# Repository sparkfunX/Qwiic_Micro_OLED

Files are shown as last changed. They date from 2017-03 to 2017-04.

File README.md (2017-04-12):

Qwiic_Micro_OLED
========================================
Qwiic Micro_OLED

[*SPX-14269*](https://www.sparkfun.com/products/14269)

The Qwiic Micro OLED is a small monochrome, blue-on-black OLED. It’s "micro", but it still packs a punch – the OLED display is crisp, and you can fit a deceivingly large amount of graphics on there. This breakout is perfect for adding graphics to your next project or displaying diagnostic information without resorting to serial output.

The Qwiic version of the Micro OLED has two Qwiic connectors that allow you to easily and quickly attach the display to the Qwicc Shield of your choosing.The [Qwiic system](http://www.sparkfun.com/qwiic) enables fast and solderless connection between popular platforms and various sensors and actuators. You can read more about the Qwiic system [here](http://www.sparkfun.com/qwiic). 

License Information
-------------------

This product is _**open source**_!

Please review the LICENSE.md file for license information.

If you have any questions or concerns on licensing, please contact techsupport@sparkfun.com.

Distributed as-is; no warranty is given.

- Your friends at SparkFun.

_<COLLABORATION CREDIT>_

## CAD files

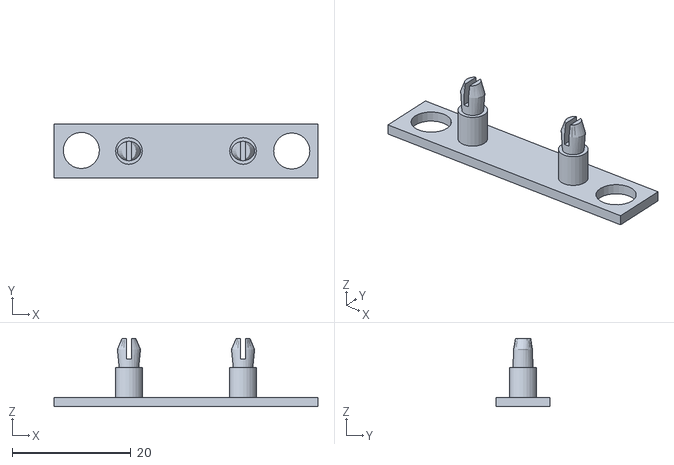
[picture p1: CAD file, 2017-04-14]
Mold/OLED_Suction_Holder.stl
44.5 x 9.18 x 11.5

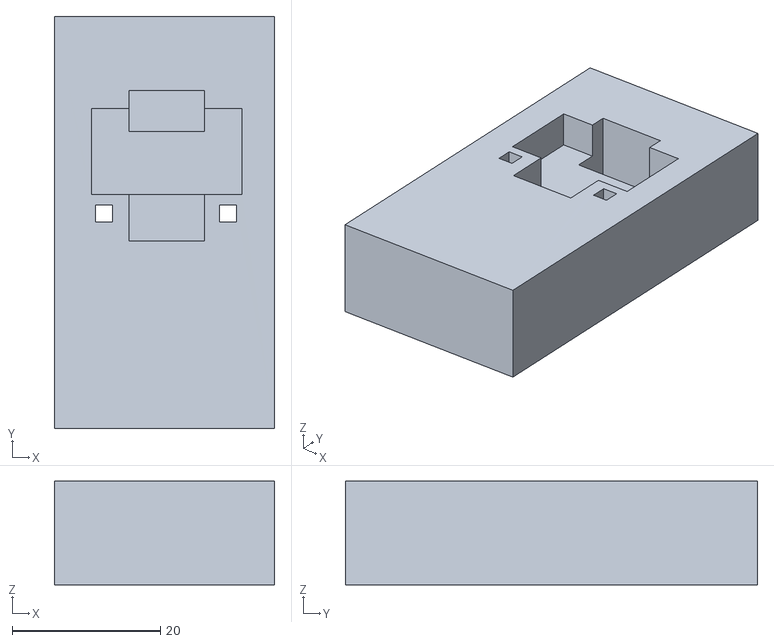
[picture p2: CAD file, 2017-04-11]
Mold/OLED_Soldering_Jig.stl
29.7 x 55.6 x 14.0

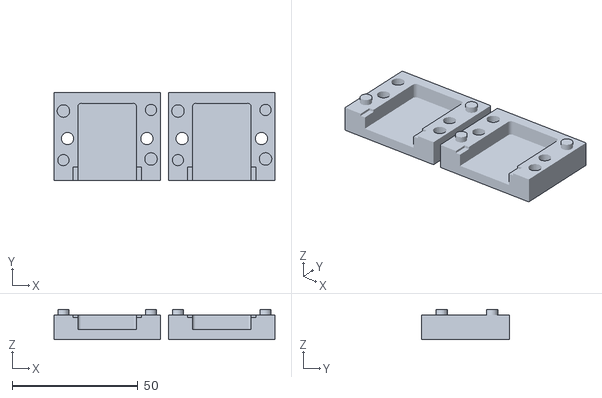
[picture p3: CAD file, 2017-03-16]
Mold/Qwiic_OLED_Mold_MillVersionV2.stl
87.9 x 35.0 x 12.0

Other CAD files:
Mold/OLED_Soldering_Jig.skp
Mold/OLED_Suction_Holder.skp
Mold/Qwiic_OLED_Mold_MillVersionV2.skp
Mold/Qwiic_OLED_Mold_MillVersionV3.skp

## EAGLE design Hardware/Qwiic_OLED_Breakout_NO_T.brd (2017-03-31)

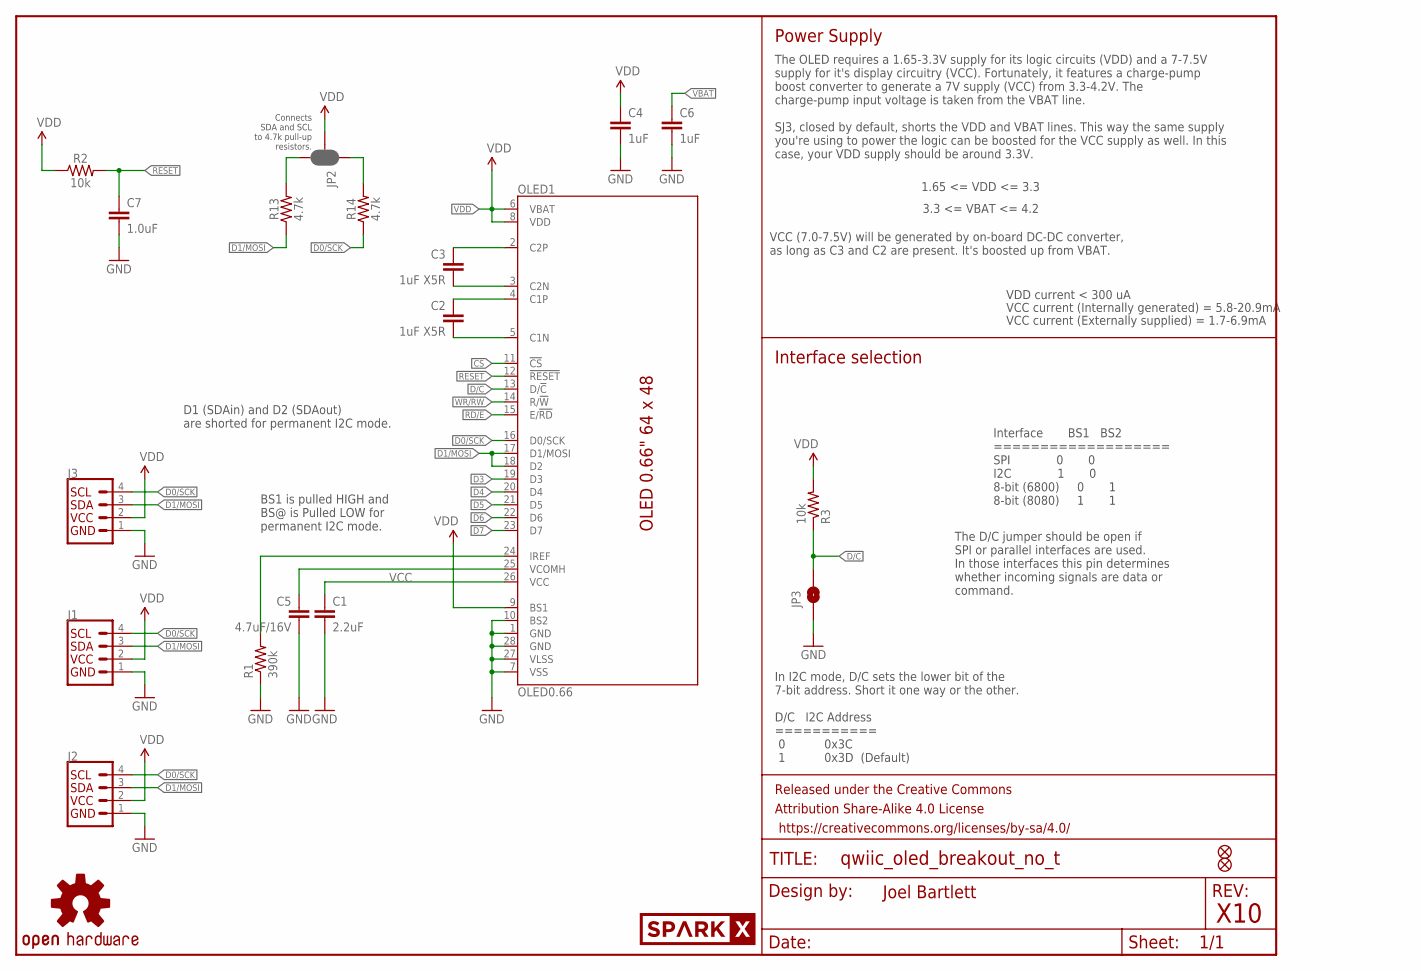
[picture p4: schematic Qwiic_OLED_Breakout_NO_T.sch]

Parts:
C1: 2.2uF; 0805
C2, C3: 1uF X5R; 0805
C4, C6: 1uF; 0603-CAP
C5: 4.7uF/16V; 1206
C7: 1.0uF; 0603
FID1, FID2: FIDUCIAL1X2; FIDUCIAL-1X2
FRAME1: FRAME-LETTER; CREATIVE_COMMONS
J1, J2: I2C_STANDARDJS-1MM; 1X04_1MM_RA
J3: I2C_STANDARD_NO_SILK; 1X04_NO_SILK
JP2: JUMPER-SMT_3_2-NC_PASTE_SILK; SMT-JUMPER_3_2-NC_PASTE_SILK
JP3: JUMPER-SMT_2_NO_SILK; SMT-JUMPER_2_NO_SILK
LOGO3: OSHW-LOGOS; OSHW-LOGO-S
OLED1: OLED0.66; OLED-0.66-64X48
R1: 390k; 0603-RES
R2: 10k; 0603
R3: 10k; 0603-RES
R13, R14: 4.7k; 0603
U$3: SPARKX-LOGO2; SPARKX-TINY

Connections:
C1N: C2.2, OLED1.5 (C1N)
C1P: C2.1, OLED1.4 (C1P)
C2N: C3.2, OLED1.3 (C2N)
C2P: C3.1, OLED1.2 (C2P)
CS: OLED1.11 (!CS!)
D0/SCK: J1.4 (SCL), J2.4 (SCL), J3.4 (SCL), OLED1.16 (D0/SCK), R14.1
D1/MOSI: J1.3 (SDA), J2.3 (SDA), J3.3 (SDA), OLED1.17 (D1/MOSI), OLED1.18 (D2), R13.1
D3: OLED1.19 (D3)
D4: OLED1.20 (D4)
D5: OLED1.21 (D5)
D6: OLED1.22 (D6)
D7: OLED1.23 (D7)
D/C: JP3.2, OLED1.13 (D/!C!), R3.1
GND: C1.2, C4.2, C5.2, C6.2, C7.2, J1.1 (GND), J2.1 (GND), J3.1 (GND), JP3.1, OLED1.1 (GND), OLED1.7 (VSS), OLED1.10 (BS2), OLED1.27 (VLSS), OLED1.28 (GND), R1.1
IREF: OLED1.24 (IREF), R1.2
unnamed: JP2.3, R13.2
unnamed: JP2.1, R14.2
RD/E: OLED1.15 (E/!RD!)
RESET: C7.1, OLED1.12 (!RESET!), R2.2
VBAT: C6.1
VCC: C1.1, OLED1.26 (VCC)
VCOMH: C5.1, OLED1.25 (VCOMH)
VDD: C4.1, J1.2 (VCC), J2.2 (VCC), J3.2 (VCC), JP2.2, OLED1.6 (VBAT), OLED1.8 (VDD), OLED1.9 (BS1), R2.1, R3.2
WR/RW: OLED1.14 (R/!W!)

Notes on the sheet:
X10
1.65 <= VDD <= 3.3
VDD current < 300 uA
VCC current (Internally generated) = 5.8-20.9mA
VCC current (Externally supplied) = 1.7-6.9mA
Interface BS1 BS2 =================== SPI 0 0 I2C 1 0 8-bit (6800) 0 1 8-bit (8080) 1 1
VCC (7.0-7.5V) will be generated by on-board DC-DC converter, as long as C3 and C2 are present. It's boosted up from VBAT.
3.3 <= VBAT <= 4.2
Interface selection
D1 (SDAin) and D2 (SDAout) are shorted for permanent I2C mode.
In I2C mode, D/C sets the lower bit of the 7-bit address. Short it one way or the other. D/C I2C Address =========== 0 0x3C 1 0x3D (Default)
Power Supply
The OLED requires a 1.65-3.3V supply for its logic circuits (VDD) and a 7-7.5V supply for it's display circuitry (VCC). Fortunately, it features a charge-pump boost converter to generate a 7V supply (VCC) from 3.3-4.2V. The charge-pump input voltage is taken from the VBAT line. SJ3, closed by defau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
The D/C jumper should be open if SPI or parallel interfaces are used. In those interfaces this pin determines whether incoming signals are data or command.
BS1 is pulled HIGH and BS@ is Pulled LOW for permanent I2C mode.
Connects SDA and SCL to 4.7k pull-up resistors.
Joel Bartlett

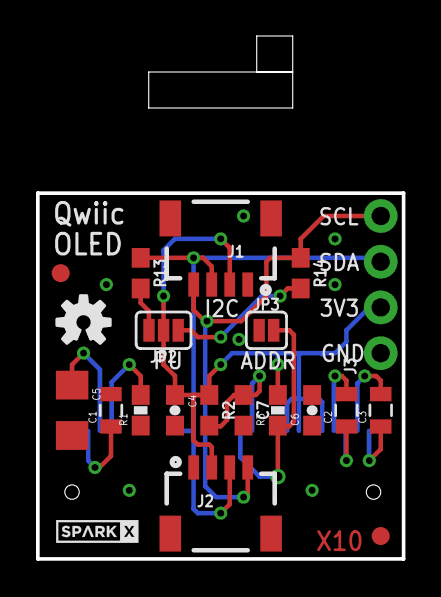
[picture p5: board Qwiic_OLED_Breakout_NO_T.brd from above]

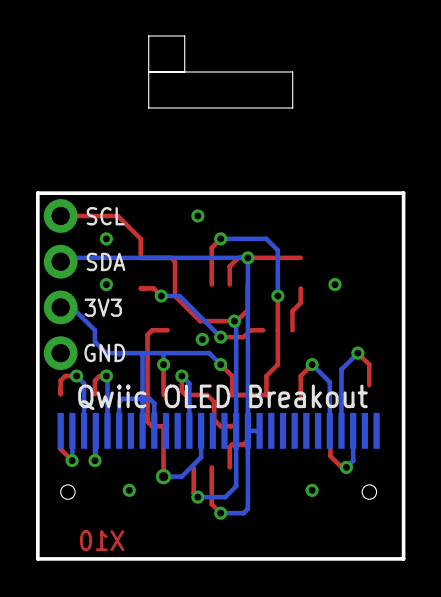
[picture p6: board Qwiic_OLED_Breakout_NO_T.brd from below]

Board: 2 copper layers, 20.3 x 20.3 mm, 23 parts (2 on the bottom side), 15 nets.

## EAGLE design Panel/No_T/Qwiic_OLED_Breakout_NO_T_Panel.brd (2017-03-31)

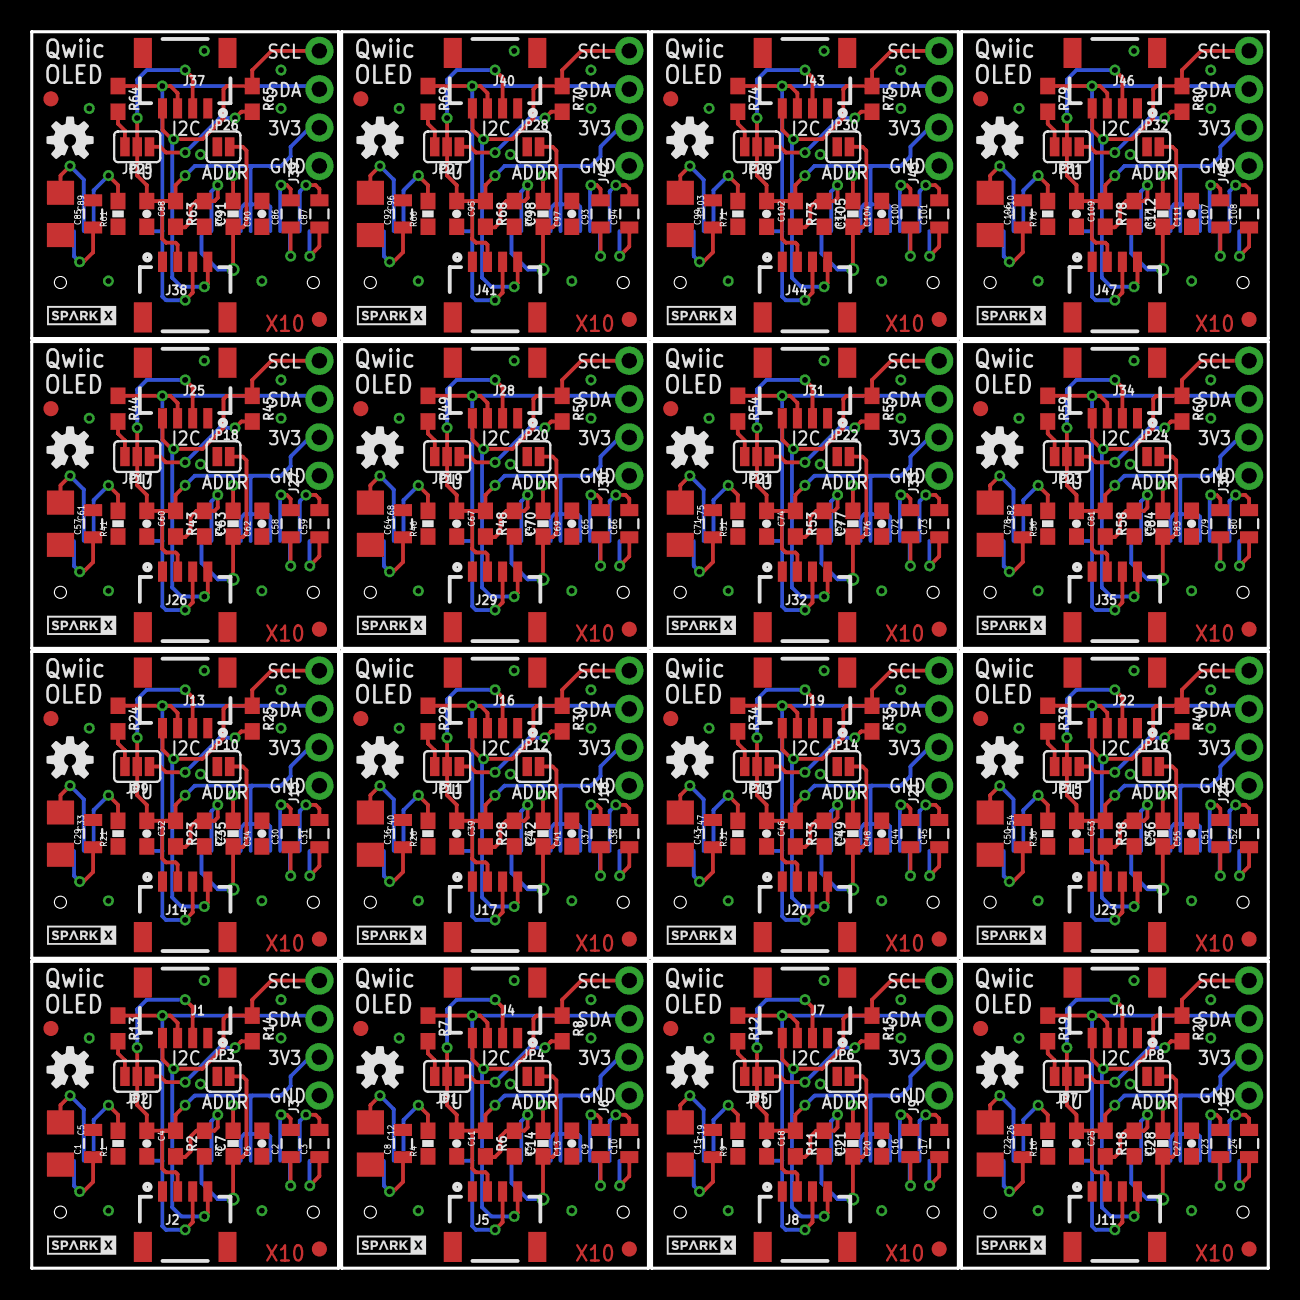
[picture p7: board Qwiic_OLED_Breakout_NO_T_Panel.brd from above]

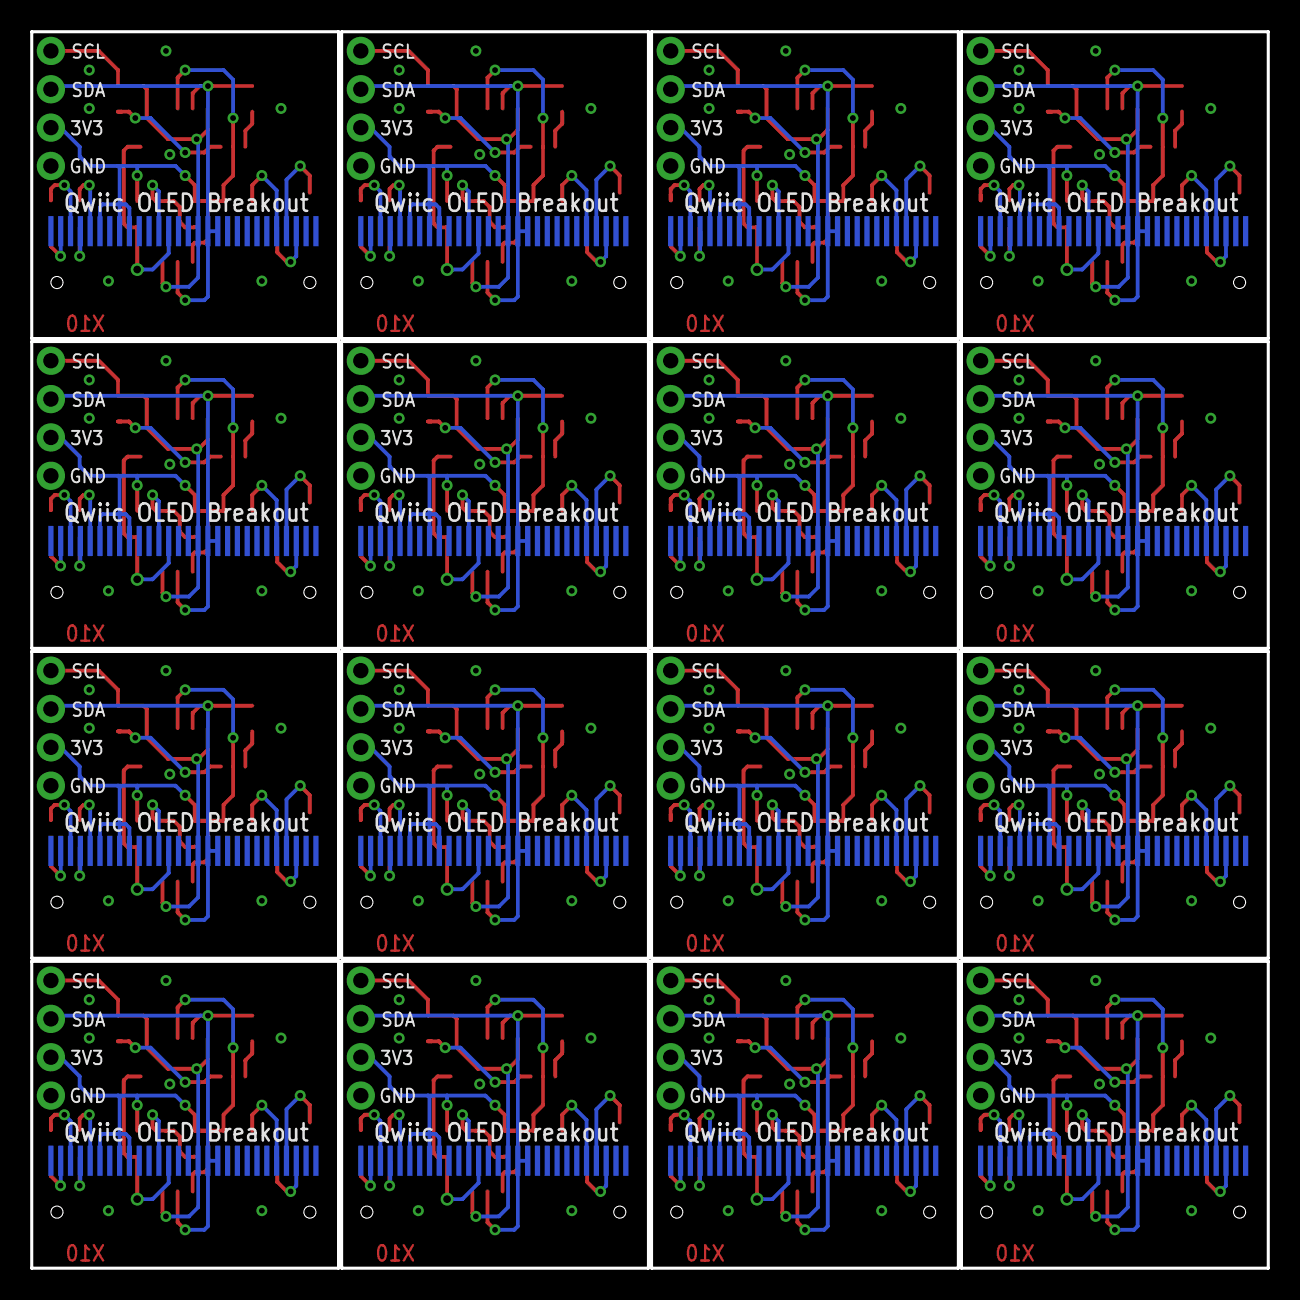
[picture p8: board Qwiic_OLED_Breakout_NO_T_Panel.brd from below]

Board: 2 copper layers, 81.9 x 81.9 mm, 352 parts (16 on the bottom side), 240 nets.

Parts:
C1, C8, C15, C22, C29, C36, C43, C50, C57, C64, C71, C78, C85, C92, C99, C106: 2.2uF; 0805
C2, C3, C9, C10, C16, C17, C23, C24, C30, C31, C37, C38, C44, C45, C51, C52, C58, C59, C65, C66, C72, C73, C79, C80, C86, C87, C93, C94, C100, C101, C107, C108: 1uF X5R; 0805
C4, C6, C11, C13, C18, C20, C25, C27, C32, C34, C39, C41, C46, C48, C53, C55, C60, C62, C67, C69, C74, C76, C81, C83, C88, C90, C95, C97, C102, C104, C109, C111: 1uF; 0603-CAP
C5, C12, C19, C26, C33, C40, C47, C54, C61, C68, C75, C82, C89, C96, C103, C110: 4.7uF/16V; 1206
C7, C14, C21, C28, C35, C42, C49, C56, C63, C70, C77, C84, C91, C98, C105, C112: 1.0uF; 0603
FID1, FID2, FID3, FID4, FID5, FID6, FID7, FID8, FID9, FID10, FID11, FID12, FID13, FID14, FID15, FID16, FID17, FID18, FID19, FID20, FID21, FID22, FID23, FID24, FID25, FID26, FID27, FID28, FID29, FID30, FID31, FID32: FIDUCIAL1X2; FIDUCIAL-1X2
J1, J2, J4, J5, J7, J8, J10, J11, J13, J14, J16, J17, J19, J20, J22, J23, J25, J26, J28, J29, J31, J32, J34, J35, J37, J38, J40, J41, J43, J44, J46, J47: 1X04_1MM_RA
J3, J6, J9, J12, J15, J18, J21, J24, J27, J30, J33, J36, J39, J42, J45, J48: 1X04_NO_SILK
JP1, JP2, JP5, JP7, JP9, JP11, JP13, JP15, JP17, JP19, JP21, JP23, JP25, JP27, JP29, JP31: SMT-JUMPER_3_2-NC_PASTE_SILK
JP3, JP4, JP6, JP8, JP10, JP12, JP14, JP16, JP18, JP20, JP22, JP24, JP26, JP28, JP30, JP32: SMT-JUMPER_2_NO_SILK
LOGO1, LOGO2, LOGO3, LOGO4, LOGO5, LOGO6, LOGO7, LOGO8, LOGO9, LOGO10, LOGO11, LOGO12, LOGO13, LOGO14, LOGO15, LOGO16: OSHW-LOGOS; OSHW-LOGO-S
OLED1, OLED2, OLED3, OLED4, OLED5, OLED6, OLED7, OLED8, OLED9, OLED10, OLED11, OLED12, OLED13, OLED14, OLED15, OLED16: OLED0.66; OLED-0.66-64X48
R1, R4, R9, R16, R21, R26, R31, R36, R41, R46, R51, R56, R61, R66, R71, R76: 390k; 0603-RES
R2, R6, R11, R18, R23, R28, R33, R38, R43, R48, R53, R58, R63, R68, R73, R78: 10k; 0603
R3, R5, R10, R17, R22, R27, R32, R37, R42, R47, R52, R57, R62, R67, R72, R77: 10k; 0603-RES
R7, R8, R12, R13, R14, R15, R19, R20, R24, R25, R29, R30, R34, R35, R39, R40, R44, R45, R49, R50, R54, R55, R59, R60, R64, R65, R69, R70, R74, R75, R79, R80: 4.7k; 0603
U$1, U$2, U$3, U$4, U$5, U$6, U$7, U$8, U$9, U$10, U$11, U$12, U$13, U$14, U$15, U$16: SPARKX-LOGO2; SPARKX-TINY

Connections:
C1N: C2.2, OLED1.5
C1N1: C9.2, OLED2.5
C1N2: C16.2, OLED3.5
C1N3: C23.2, OLED4.5
C1N4: C30.2, OLED5.5
C1N5: C37.2, OLED6.5
C1N6: C44.2, OLED7.5
C1N7: C51.2, OLED8.5
C1N8: C58.2, OLED9.5
C1N9: C65.2, OLED10.5
C1N10: C72.2, OLED11.5
C1N11: C79.2, OLED12.5
C1N12: C86.2, OLED13.5
C1N13: C93.2, OLED14.5
C1N14: C100.2, OLED15.5
C1N15: C107.2, OLED16.5
C1P: C2.1, OLED1.4
C1P1: C9.1, OLED2.4
C1P2: C16.1, OLED3.4
C1P3: C23.1, OLED4.4
C1P4: C30.1, OLED5.4
C1P5: C37.1, OLED6.4
C1P6: C44.1, OLED7.4
C1P7: C51.1, OLED8.4
C1P8: C58.1, OLED9.4
C1P9: C65.1, OLED10.4
C1P10: C72.1, OLED11.4
C1P11: C79.1, OLED12.4
C1P12: C86.1, OLED13.4
C1P13: C93.1, OLED14.4
C1P14: C100.1, OLED15.4
C1P15: C107.1, OLED16.4
C2N: C3.2, OLED1.3
C2N1: C10.2, OLED2.3
C2N2: C17.2, OLED3.3
C2N3: C24.2, OLED4.3
C2N4: C31.2, OLED5.3
C2N5: C38.2, OLED6.3
C2N6: C45.2, OLED7.3
C2N7: C52.2, OLED8.3
C2N8: C59.2, OLED9.3
C2N9: C66.2, OLED10.3
C2N10: C73.2, OLED11.3
C2N11: C80.2, OLED12.3
C2N12: C87.2, OLED13.3
C2N13: C94.2, OLED14.3
C2N14: C101.2, OLED15.3
C2N15: C108.2, OLED16.3
C2P: C3.1, OLED1.2
C2P1: C10.1, OLED2.2
C2P2: C17.1, OLED3.2
C2P3: C24.1, OLED4.2
C2P4: C31.1, OLED5.2
C2P5: C38.1, OLED6.2
C2P6: C45.1, OLED7.2
C2P7: C52.1, OLED8.2
C2P8: C59.1, OLED9.2
C2P9: C66.1, OLED10.2
C2P10: C73.1, OLED11.2
C2P11: C80.1, OLED12.2
C2P12: C87.1, OLED13.2
C2P13: C94.1, OLED14.2
C2P14: C101.1, OLED15.2
C2P15: C108.1, OLED16.2
D0/SCK: J1.4, J2.4, J3.4, OLED1.16, R14.1
D0/SCK1: J4.4, J5.4, J6.4, OLED2.16, R8.1
D0/SCK2: J7.4, J8.4, J9.4, OLED3.16, R15.1
D0/SCK3: J10.4, J11.4, J12.4, OLED4.16, R20.1
D0/SCK4: J13.4, J14.4, J15.4, OLED5.16, R25.1
D0/SCK5: J16.4, J17.4, J18.4, OLED6.16, R30.1
D0/SCK6: J19.4, J20.4, J21.4, OLED7.16, R35.1
D0/SCK7: J22.4, J23.4, J24.4, OLED8.16, R40.1
D0/SCK8: J25.4, J26.4, J27.4, OLED9.16, R45.1
D0/SCK9: J28.4, J29.4, J30.4, OLED10.16, R50.1
D0/SCK10: J31.4, J32.4, J33.4, OLED11.16, R55.1
D0/SCK11: J34.4, J35.4, J36.4, OLED12.16, R60.1
D0/SCK12: J37.4, J38.4, J39.4, OLED13.16, R65.1
D0/SCK13: J40.4, J41.4, J42.4, OLED14.16, R70.1
D0/SCK14: J43.4, J44.4, J45.4, OLED15.16, R75.1
D0/SCK15: J46.4, J47.4, J48.4, OLED16.16, R80.1
D1/MOSI: J1.3, J2.3, J3.3, OLED1.17, OLED1.18, R13.1
D1/MOSI1: J4.3, J5.3, J6.3, OLED2.17, OLED2.18, R7.1
D1/MOSI2: J7.3, J8.3, J9.3, OLED3.17, OLED3.18, R12.1
D1/MOSI3: J10.3, J11.3, J12.3, OLED4.17, OLED4.18, R19.1
D1/MOSI4: J13.3, J14.3, J15.3, OLED5.17, OLED5.18, R24.1
D1/MOSI5: J16.3, J17.3, J18.3, OLED6.17, OLED6.18, R29.1
D1/MOSI6: J19.3, J20.3, J21.3, OLED7.17, OLED7.18, R34.1
D1/MOSI7: J22.3, J23.3, J24.3, OLED8.17, OLED8.18, R39.1
D1/MOSI8: J25.3, J26.3, J27.3, OLED9.17, OLED9.18, R44.1
D1/MOSI9: J28.3, J29.3, J30.3, OLED10.17, OLED10.18, R49.1
D1/MOSI10: J31.3, J32.3, J33.3, OLED11.17, OLED11.18, R54.1
D1/MOSI11: J34.3, J35.3, J36.3, OLED12.17, OLED12.18, R59.1
D1/MOSI12: J37.3, J38.3, J39.3, OLED13.17, OLED13.18, R64.1
D1/MOSI13: J40.3, J41.3, J42.3, OLED14.17, OLED14.18, R69.1
D1/MOSI14: J43.3, J44.3, J45.3, OLED15.17, OLED15.18, R74.1
D1/MOSI15: J46.3, J47.3, J48.3, OLED16.17, OLED16.18, R79.1
D/C: JP3.2, OLED1.13, R3.1
D/C1: JP4.2, OLED2.13, R5.1
D/C2: JP6.2, OLED3.13, R10.1
D/C3: JP8.2, OLED4.13, R17.1
D/C4: JP10.2, OLED5.13, R22.1
D/C5: JP12.2, OLED6.13, R27.1
D/C6: JP14.2, OLED7.13, R32.1
D/C7: JP16.2, OLED8.13, R37.1
D/C8: JP18.2, OLED9.13, R42.1
D/C9: JP20.2, OLED10.13, R47.1
D/C10: JP22.2, OLED11.13, R52.1
D/C11: JP24.2, OLED12.13, R57.1
D/C12: JP26.2, OLED13.13, R62.1
D/C13: JP28.2, OLED14.13, R67.1
D/C14: JP30.2, OLED15.13, R72.1
D/C15: JP32.2, OLED16.13, R77.1
GND: C1.2, C4.2, C5.2, C6.2, C7.2, J1.1, J2.1, J3.1, JP3.1, OLED1.1, OLED1.7, OLED1.10, OLED1.27, OLED1.28, R1.1
GND1: C8.2, C11.2, C12.2, C13.2, C14.2, J4.1, J5.1, J6.1, JP4.1, OLED2.1, OLED2.7, OLED2.10, OLED2.27, OLED2.28, R4.1
GND2: C15.2, C18.2, C19.2, C20.2, C21.2, J7.1, J8.1, J9.1, JP6.1, OLED3.1, OLED3.7, OLED3.10, OLED3.27, OLED3.28, R9.1
GND3: C22.2, C25.2, C26.2, C27.2, C28.2, J10.1, J11.1, J12.1, JP8.1, OLED4.1, OLED4.7, OLED4.10, OLED4.27, OLED4.28, R16.1
GND4: C29.2, C32.2, C33.2, C34.2, C35.2, J13.1, J14.1, J15.1, JP10.1, OLED5.1, OLED5.7, OLED5.10, OLED5.27, OLED5.28, R21.1
GND5: C36.2, C39.2, C40.2, C41.2, C42.2, J16.1, J17.1, J18.1, JP12.1, OLED6.1, OLED6.7, OLED6.10, OLED6.27, OLED6.28, R26.1
GND6: C43.2, C46.2, C47.2, C48.2, C49.2, J19.1, J20.1, J21.1, JP14.1, OLED7.1, OLED7.7, OLED7.10, OLED7.27, OLED7.28, R31.1
GND7: C50.2, C53.2, C54.2, C55.2, C56.2, J22.1, J23.1, J24.1, JP16.1, OLED8.1, OLED8.7, OLED8.10, OLED8.27, OLED8.28, R36.1
GND8: C57.2, C60.2, C61.2, C62.2, C63.2, J25.1, J26.1, J27.1, JP18.1, OLED9.1, OLED9.7, OLED9.10, OLED9.27, OLED9.28, R41.1
GND9: C64.2, C67.2, C68.2, C69.2, C70.2, J28.1, J29.1, J30.1, JP20.1, OLED10.1, OLED10.7, OLED10.10, OLED10.27, OLED10.28, R46.1
GND10: C71.2, C74.2, C75.2, C76.2, C77.2, J31.1, J32.1, J33.1, JP22.1, OLED11.1, OLED11.7, OLED11.10, OLED11.27, OLED11.28, R51.1
GND11: C78.2, C81.2, C82.2, C83.2, C84.2, J34.1, J35.1, J36.1, JP24.1, OLED12.1, OLED12.7, OLED12.10, OLED12.27, OLED12.28, R56.1
GND12: C85.2, C88.2, C89.2, C90.2, C91.2, J37.1, J38.1, J39.1, JP26.1, OLED13.1, OLED13.7, OLED13.10, OLED13.27, OLED13.28, R61.1
GND13: C92.2, C95.2, C96.2, C97.2, C98.2, J40.1, J41.1, J42.1, JP28.1, OLED14.1, OLED14.7, OLED14.10, OLED14.27, OLED14.28, R66.1
GND14: C99.2, C102.2, C103.2, C104.2, C105.2, J43.1, J44.1, J45.1, JP30.1, OLED15.1, OLED15.7, OLED15.10, OLED15.27, OLED15.28, R71.1
GND15: C106.2, C109.2, C110.2, C111.2, C112.2, J46.1, J47.1, J48.1, JP32.1, OLED16.1, OLED16.7, OLED16.10, OLED16.27, OLED16.28, R76.1
IREF: OLED1.24, R1.2
IREF1: OLED2.24, R4.2
IREF2: OLED3.24, R9.2
IREF3: OLED4.24, R16.2
IREF4: OLED5.24, R21.2
IREF5: OLED6.24, R26.2
IREF6: OLED7.24, R31.2
IREF7: OLED8.24, R36.2
IREF8: OLED9.24, R41.2
IREF9: OLED10.24, R46.2
IREF10: OLED11.24, R51.2
IREF11: OLED12.24, R56.2
IREF12: OLED13.24, R61.2
IREF13: OLED14.24, R66.2
IREF14: OLED15.24, R71.2
IREF15: OLED16.24, R76.2
unnamed: JP1.3, R7.2
unnamed: JP1.1, R8.2
unnamed: JP5.3, R12.2
unnamed: JP2.3, R13.2
unnamed: JP2.1, R14.2
unnamed: JP5.1, R15.2
unnamed: JP7.3, R19.2
unnamed: JP7.1, R20.2
unnamed: JP9.3, R24.2
unnamed: JP9.1, R25.2
unnamed: JP11.3, R29.2
unnamed: JP11.1, R30.2
unnamed: JP13.3, R34.2
unnamed: JP13.1, R35.2
unnamed: JP15.3, R39.2
unnamed: JP15.1, R40.2
unnamed: JP17.3, R44.2
unnamed: JP17.1, R45.2
unnamed: JP19.3, R49.2
unnamed: JP19.1, R50.2
unnamed: JP21.3, R54.2
unnamed: JP21.1, R55.2
unnamed: JP23.3, R59.2
unnamed: JP23.1, R60.2
unnamed: JP25.3, R64.2
unnamed: JP25.1, R65.2
unnamed: JP27.3, R69.2
unnamed: JP27.1, R70.2
unnamed: JP29.3, R74.2
unnamed: JP29.1, R75.2
unnamed: JP31.3, R79.2
unnamed: JP31.1, R80.2
RESET: C7.1, OLED1.12, R2.2
RESET1: C14.1, OLED2.12, R6.2
RESET2: C21.1, OLED3.12, R11.2
RESET3: C28.1, OLED4.12, R18.2
RESET4: C35.1, OLED5.12, R23.2
RESET5: C42.1, OLED6.12, R28.2
RESET6: C49.1, OLED7.12, R33.2
RESET7: C56.1, OLED8.12, R38.2
RESET8: C63.1, OLED9.12, R43.2
RESET9: C70.1, OLED10.12, R48.2
RESET10: C77.1, OLED11.12, R53.2
RESET11: C84.1, OLED12.12, R58.2
RESET12: C91.1, OLED13.12, R63.2
RESET13: C98.1, OLED14.12, R68.2
RESET14: C105.1, OLED15.12, R73.2
RESET15: C112.1, OLED16.12, R78.2
VCC: C1.1, OLED1.26
VCC1: C8.1, OLED2.26
VCC2: C15.1, OLED3.26
VCC3: C22.1, OLED4.26
VCC4: C29.1, OLED5.26
VCC5: C36.1, OLED6.26
VCC6: C43.1, OLED7.26
VCC7: C50.1, OLED8.26
VCC8: C57.1, OLED9.26
VCC9: C64.1, OLED10.26
VCC10: C71.1, OLED11.26
VCC11: C78.1, OLED12.26
VCC12: C85.1, OLED13.26
VCC13: C92.1, OLED14.26
VCC14: C99.1, OLED15.26
VCC15: C106.1, OLED16.26
VCOMH: C5.1, OLED1.25
VCOMH1: C12.1, OLED2.25
VCOMH2: C19.1, OLED3.25
VCOMH3: C26.1, OLED4.25
VCOMH4: C33.1, OLED5.25
VCOMH5: C40.1, OLED6.25
VCOMH6: C47.1, OLED7.25
VCOMH7: C54.1, OLED8.25
VCOMH8: C61.1, OLED9.25
VCOMH9: C68.1, OLED10.25
VCOMH10: C75.1, OLED11.25
VCOMH11: C82.1, OLED12.25
VCOMH12: C89.1, OLED13.25
VCOMH13: C96.1, OLED14.25
VCOMH14: C103.1, OLED15.25
VCOMH15: C110.1, OLED16.25
VDD: C4.1, J1.2, J2.2, J3.2, JP2.2, OLED1.6, OLED1.8, OLED1.9, R2.1, R3.2
VDD1: C11.1, J4.2, J5.2, J6.2, JP1.2, OLED2.6, OLED2.8, OLED2.9, R5.2, R6.1
VDD2: C18.1, J7.2, J8.2, J9.2, JP5.2, OLED3.6, OLED3.8, OLED3.9, R10.2, R11.1
VDD3: C25.1, J10.2, J11.2, J12.2, JP7.2, OLED4.6, OLED4.8, OLED4.9, R17.2, R18.1
VDD4: C32.1, J13.2, J14.2, J15.2, JP9.2, OLED5.6, OLED5.8, OLED5.9, R22.2, R23.1
VDD5: C39.1, J16.2, J17.2, J18.2, JP11.2, OLED6.6, OLED6.8, OLED6.9, R27.2, R28.1
VDD6: C46.1, J19.2, J20.2, J21.2, JP13.2, OLED7.6, OLED7.8, OLED7.9, R32.2, R33.1
VDD7: C53.1, J22.2, J23.2, J24.2, JP15.2, OLED8.6, OLED8.8, OLED8.9, R37.2, R38.1
VDD8: C60.1, J25.2, J26.2, J27.2, JP17.2, OLED9.6, OLED9.8, OLED9.9, R42.2, R43.1
VDD9: C67.1, J28.2, J29.2, J30.2, JP19.2, OLED10.6, OLED10.8, OLED10.9, R47.2, R48.1
VDD10: C74.1, J31.2, J32.2, J33.2, JP21.2, OLED11.6, OLED11.8, OLED11.9, R52.2, R53.1
VDD11: C81.1, J34.2, J35.2, J36.2, JP23.2, OLED12.6, OLED12.8, OLED12.9, R57.2, R58.1
VDD12: C88.1, J37.2, J38.2, J39.2, JP25.2, OLED13.6, OLED13.8, OLED13.9, R62.2, R63.1
VDD13: C95.1, J40.2, J41.2, J42.2, JP27.2, OLED14.6, OLED14.8, OLED14.9, R67.2, R68.1
VDD14: C102.1, J43.2, J44.2, J45.2, JP29.2, OLED15.6, OLED15.8, OLED15.9, R72.2, R73.1
VDD15: C109.1, J46.2, J47.2, J48.2, JP31.2, OLED16.6, OLED16.8, OLED16.9, R77.2, R78.1

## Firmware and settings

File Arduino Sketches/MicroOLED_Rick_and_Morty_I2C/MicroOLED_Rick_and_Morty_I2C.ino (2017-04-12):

/******************************************************************************
 * MicroOLED_Demo.ino
 * SFE_MicroOLED Library Demo
 * Jim Lindblom @ SparkFun Electronics
 * Original Creation Date: October 27, 2014
 * 
 * This sketch uses the MicroOLED library to draw bitmaps to the OLED 
 * 
 * This example was modified for the Qwiic Micro OLED
 * Joel Bartlett
 * 04/12/17
 * 
 * Development environment specifics:
 *  Arduino 1.0.5
 *  Arduino Pro 3.3V
 *  Micro OLED Breakout v1.0
 * 
 * This code is beerware; if you see me (or any other SparkFun employee) at the
 * local, and you've found our code helpful, please buy us a round!
 * 
 * Distributed as-is; no warranty is given.
 ******************************************************************************/
#include <Wire.h>  // Include Wire if you're using I2C
#include <SFE_MicroOLED.h>  // Include the SFE_MicroOLED library
#include "bitmaps.h"

//////////////////////////
// MicroOLED Definition //
//////////////////////////
//The library assumes a reset pin is necessary. The Qwiic OLED has RST hard-wired, so pick an arbitrarty IO pin that is not being used
#define PIN_RESET 9  
//The DC_JUMPER is the I2C Address Select jumper. Set to 1 if the jumper is open (Default), or set to 0 if it's closed.
#define DC_JUMPER 1

//////////////////////////////////
// MicroOLED Object Declaration //
//////////////////////////////////
MicroOLED oled(PIN_RESET, DC_JUMPER);    // I2C declaration

void setup()
{
  delay(100);
  oled.begin();    // Initialize the OLED
  oled.clear(ALL); // Clear the display's internal memory
  oled.display();  // Display what's in the buffer (splashscreen)
  delay(1000);     // Delay 1000 ms
  oled.clear(PAGE); // Clear the buffer.
  
}
//---------------------------------------------------------------
void loop()
{
    drawRick();
    delay(5000);
    drawMorty();
    delay(5000);
}
//---------------------------------------------------------------
void drawRick()
{
    oled.clear(ALL);
    oled.clear(PAGE);
    oled.drawBitmap(rick);//Display Logo
    oled.display();
}
//---------------------------------------------------------------

void drawMorty()
{
    oled.clear(ALL);
    oled.clear(PAGE);
    oled.drawBitmap(morty);//Display Logo
    oled.display();
}

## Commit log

2017-03-14 More mold modifications Elongated the PCB for mold
    [Micro-OLED_I2C.brd, Micro-OLED_I2C_Mill_Humid_Test.brd, Qwiic_OLED_Mold_Single.skp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]
2017-03-16 Mold V2
    [Micro-OLED_I2C_Mill_Humid_Test.brd, Micro-OLED_I2C_Mill_Humid_Test.sch, Qwiic_OLED_Breakout.brd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]
2017-03-31 Adding Gerbers
    [Qwiic_OLED_Breakout_NO_T.brd, Qwiic_OLED_Breakout_NO_T.sch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]
2017-04-11 Added soldering jig
    [OLED_Soldering_Jig.skp, OLED_Soldering_Jig.stl, OLED_Soldering_Jig~.skp]
2017-04-12 Adding product page files
    [Qwiic_OLED_Breakout_NO_T.sch]
2017-04-12 Cleanup repo
    [Micro-OLED_I2C_Mill_Humid_Test.brd, Micro-OLED_I2C_Mill_Humid_Test.sch, OLED_Soldering_Jig~.skp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]
2017-04-14 Adding suction cup holder
    [OLED_Suction_Holder.skp, OLED_Suction_Holder.stl, Qwiic_OLED_Mold_MillVersionV3.skp]

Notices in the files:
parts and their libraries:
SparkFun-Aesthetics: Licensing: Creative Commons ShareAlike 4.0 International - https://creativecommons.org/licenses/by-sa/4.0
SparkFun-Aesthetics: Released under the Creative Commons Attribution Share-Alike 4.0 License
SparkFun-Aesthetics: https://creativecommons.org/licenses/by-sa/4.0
